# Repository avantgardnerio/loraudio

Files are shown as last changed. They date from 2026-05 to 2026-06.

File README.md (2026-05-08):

# open-oswst

Stealth LoRa radio mesh where the primary design principle is "only speak when spoken to".

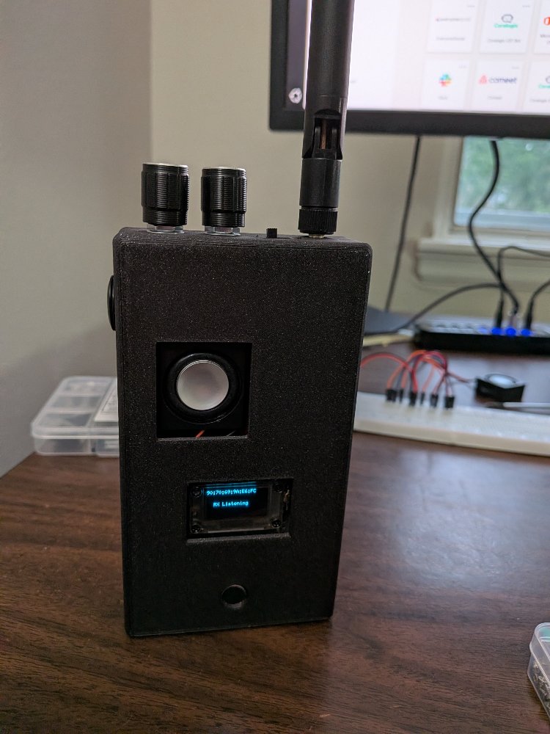
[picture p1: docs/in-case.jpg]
open-oswst radio in 3d printed case


## Hardware

- **Board**: [Heltec WiFi LoRa 32 V4](https://heltec.org/project/wifi-lora-32-v4/) (ESP32-S3 + SX1262, 863-928 MHz)
- **MCU**: ESP32-S3 rev 0.2, 16MB flash, 338 KiB RAM
- **Radio**: Semtech SX1262 LoRa transceiver, 915 MHz ISM band
- **Display**: SSD1306 128x64 OLED (I2C)

### Pin Map

| Function | GPIO |
|---|---|
| PRG button (PTT) | 0 (active LOW, internal pull-up) |
| White LED | 35 |
| Vext power enable | 36 (LOW = on) |
| OLED SDA | 17 |
| OLED SCL | 18 |
| OLED RST | 21 |
| LoRa SCK | 9 |
| LoRa MOSI | 10 |
| LoRa MISO | 11 |
| LoRa NSS | 8 |
| LoRa RST | 12 |
| LoRa DIO1 | 14 |
| LoRa BUSY | 13 |

## Dev Environment Setup

### Prerequisites

1. **Install Rust + Xtensa toolchain** via [espup](https://github.com/esp-rs/espup):

```bash
cargo install espup
espup install
```

2. **Create an ESP environment export script** (`~/export-esp.sh`):

```bash
export LIBCLANG_PATH="$HOME/.rustup/toolchains/esp/xtensa-esp32-elf-clang/esp-20.1.1_20250829/esp-clang/lib"
export PATH="$HOME/.rustup/toolchains/esp/xtensa-esp-elf/esp-15.2.0_20250920/xtensa-esp-elf/bin:$PATH"
```

The exact paths may vary — check `~/.rustup/toolchains/esp/` after `espup install`.

3. **Install flashing tools**:

```bash
cargo install espflash cargo-espflash ldproxy
```

4. **Optional**: install `picocom` for serial monitoring:

```bash
sudo apt install picocom
```

### Build

```bash
. ~/export-esp.sh
cargo build
```

ESP-IDF v5.5.x is downloaded automatically by `esp-idf-sys` on first build (takes a while).

### Flash

The firmware uses a custom partition table with a dedicated `open-oswst` NVS partition for device config. Since `espflash flash` overwrites the partition table with its own, you must re-write ours after flashing:

```bash
. ~/export-esp.sh

# 1. Flash firmware
espflash flash -p /dev/ttyACM0 target/xtensa-esp32s3-espidf/debug/open-oswst

# 2. Overwrite partition table with ours (espflash clobbers it in step 1)
espflash write-bin -p /dev/ttyACM0 0x8000 target/xtensa-esp32s3-espidf/debug/partition-table.bin

# 3. Write device config (only needed on first flash or to change config)
espflash write-bin -p /dev/ttyACM0 0xfad000 ~/phy/open-oswst_nvs.bin
```

Monitor separately:

```bash
picocom /dev/ttyACM0 -b 115200
```

### Device Config (NVS)

Device configuration lives in a dedicated `open-oswst` NVS partition at `0xfad000` (12KB), separate from the system NVS (PHY cal, WiFi, etc).

Generate a config image from `nvs_open-oswst.csv`:

```bash
# Generate NVS image (edit nvs_open-oswst.csv to change values)
python3 .embuild/espressif/python_env/idf5.5_py3.13_env/lib/python3.13/site-packages/esp_idf_nvs_partition_gen/nvs_partition_gen.py \
    generate nvs_open-oswst.csv ~/phy/open-oswst_nvs.bin 0x3000

# Flash to board
espflash write-bin -p /dev/ttyACM0 0xfad000 ~/phy/open-oswst_nvs.bin
```

Current config keys (namespace `config`):

| Key | Type | Values | Default |
|-----|---|---|---|
| `repeater` | u8 | 0=endpoint, 1=repeater | 0 |

There is also `nvs_config.py` for read-modify-write of the *system* NVS partition (preserving PHY cal data etc), but the dedicated partition approach above is preferred.

## Current Behavior

- Simplex push-to-talk voice radio over LoRa
- Hold **PRG button** (GPIO 0) to talk — audio is captured, Codec2-encoded at 1200 bps, and streamed as 4-frame LoRa packets (160ms audio each)
- Release to listen — received audio is decoded and played through I2S speaker (MAX98357A)
- OLED shows mode (RX Listening / TX Streaming / RX Audio) with RSSI and SNR on receive
- CSMA with preamble-aware jitter for collision avoidance
- Per-device config via dedicated NVS partition (repeater mode flag)
- **Next up**: repeater mesh relay

## Key Implementation Notes

- **Framework**: esp-idf-svc 0.52.1 (std Rust, not bare-metal)
- **Async**: `block_on` + `embassy_futures::select` for zero-polling PTT/RX racing
- **LoRa driver**: `lora-phy` (upstream git, 3.0.2-alpha) with `GenericSx126xInterfaceVariant`
- **GPIO type erasure**: `degrade_input()`/`degrade_output()` required for lora-phy's generic interface
- **SPI async**: `CONFIG_SPI_MASTER_ISR_IN_IRAM` disabled in `sdkconfig.defaults`
- **defmt workaround**: `defmt-discard.x` linker script discards defmt sections that break ESP-IDF flash layout
- **Stack**: 65536 bytes for main task (Codec2 init needs large stack temporaries)

## Project Structure

```
src/main.rs          # Entry point, channels, NVS config read
src/radio.rs         # SPI + LoRa init, IRQ-driven RX/TX loop, CSMA
src/app.rs           # PTT, ADC, OLED, Codec2, I2S speaker
partitions.csv       # Custom partition table (adds open-oswst NVS)
nvs_open-oswst.csv     # Default device config values
nvs_config.py        # Tool for read-modify-write of system NVS
sdkconfig.defaults   # ESP-IDF config overrides
defmt-discard.x      # Linker script to discard defmt sections
rust-toolchain.toml  # Pins to "esp" toolchain channel
build.rs             # Links defmt-discard.x
```

## Bill of Materials

### Handset (~$122)

| Component | Part | Qty | Est. Cost |
|---|---|-----|---|
| [MCU + LoRa + GPS](https://www.amazon.com/dp/B0GCD9W6JZ?ref=ppx_yo2ov_dt_b_fed_asin_title&th=1) | Heltec WiFi LoRa 32 V4 | 1 | $42 |
| [RF amplifier](https://www.amazon.com/dp/B0DQBJVR91?ref=ppx_yo2ov_dt_b_fed_asin_title) | AB-IOT-868 "Air Buddy" (902-928 MHz, bidirectional TX+LNA) | 1 | $26 |
| [Speaker amp](https://www.amazon.com/dp/B0DPJRLMDJ?ref=ppx_yo2ov_dt_b_fed_asin_title) | MAX98357A I2S Class D breakout | 1 | $3 |
| [Speaker](https://www.amazon.com/dp/B0BTP67F81?ref=ppx_yo2ov_dt_b_fed_asin_title&th=1) | 8 ohm 1W mini (JST-PH1.25mm) | 1 | $2.50 |
| [Microphone](https://www.amazon.com/dp/B0B7SP6GYX?ref=ppx_yo2ov_dt_b_fed_asin_title) | MAX9814 electret with AGC (analog out) | 1 | $4 |
| [Antenna](https://www.amazon.com/dp/B0D47HVCK7?ref=ppx_yo2ov_dt_b_fed_asin_title&th=1) | 5 dBi SMA whip (915 MHz) | 1 | $6 |
| [Battery](https://www.amazon.com/dp/B0FPCWFFYB?ref=ppx_yo2ov_dt_b_fed_asin_title) | YELUFT 1S 103450 3.7V 2000mAh LiPo (JST 1.25) | 1 | $24 |
| [encoder](https://www.amazon.com/dp/B07F24TRYG?ref=ppx_yo2ov_dt_b_fed_asin_title) | EC11 rotary encoder w/ push button (Taiss) | 2 | $1.25 |
| [Power switch](https://www.amazon.com/dp/B0DN69L9SG?ref=ppx_yo2ov_dt_b_fed_asin_title&th=1) | SS12F15 mini slide switch (SPDT) | 1 | $0.30 |
| [PTT button](https://www.amazon.com/dp/B015X34IP6?ref=ppx_yo2ov_dt_b_fed_asin_title&th=1) | Ulincos U16A1 16mm metal momentary, flush | 1 | $8 |
| [Speaker jack](https://www.amazon.com/dp/B01ASF0LW8?ref=ppx_yo2ov_dt_b_fed_asin_title) | 2.5mm TRS chassis mount (Calrad 30-714 or similar) | 1 | $0.66 |
| [Mic/PTT jack](https://www.amazon.com/dp/B00ZYWJ1DG?ref=ppx_yo2ov_dt_b_fed_asin_title) | 3.5mm TRS chassis mount w/ switch (CESS) | 1 | $2 |
| [F2F SMA](https://www.amazon.com/dp/B0FB3R5WRL?ref=ppx_yo2ov_dt_b_fed_asin_title&th=1) | Female to Female SMA | 1 | $1 |

## License

TBD

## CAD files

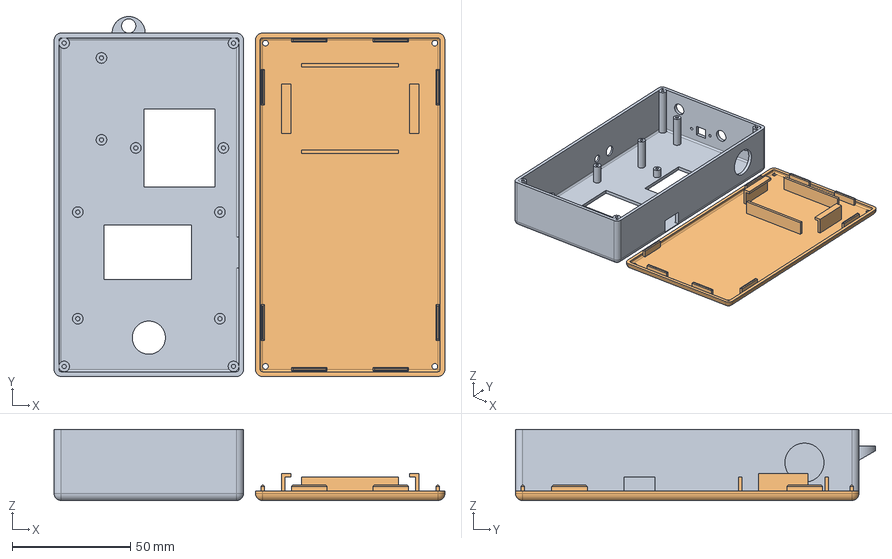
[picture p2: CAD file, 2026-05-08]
models/case.step
165.0 x 152.0 x 30.0 mm

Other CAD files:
models/case.stl

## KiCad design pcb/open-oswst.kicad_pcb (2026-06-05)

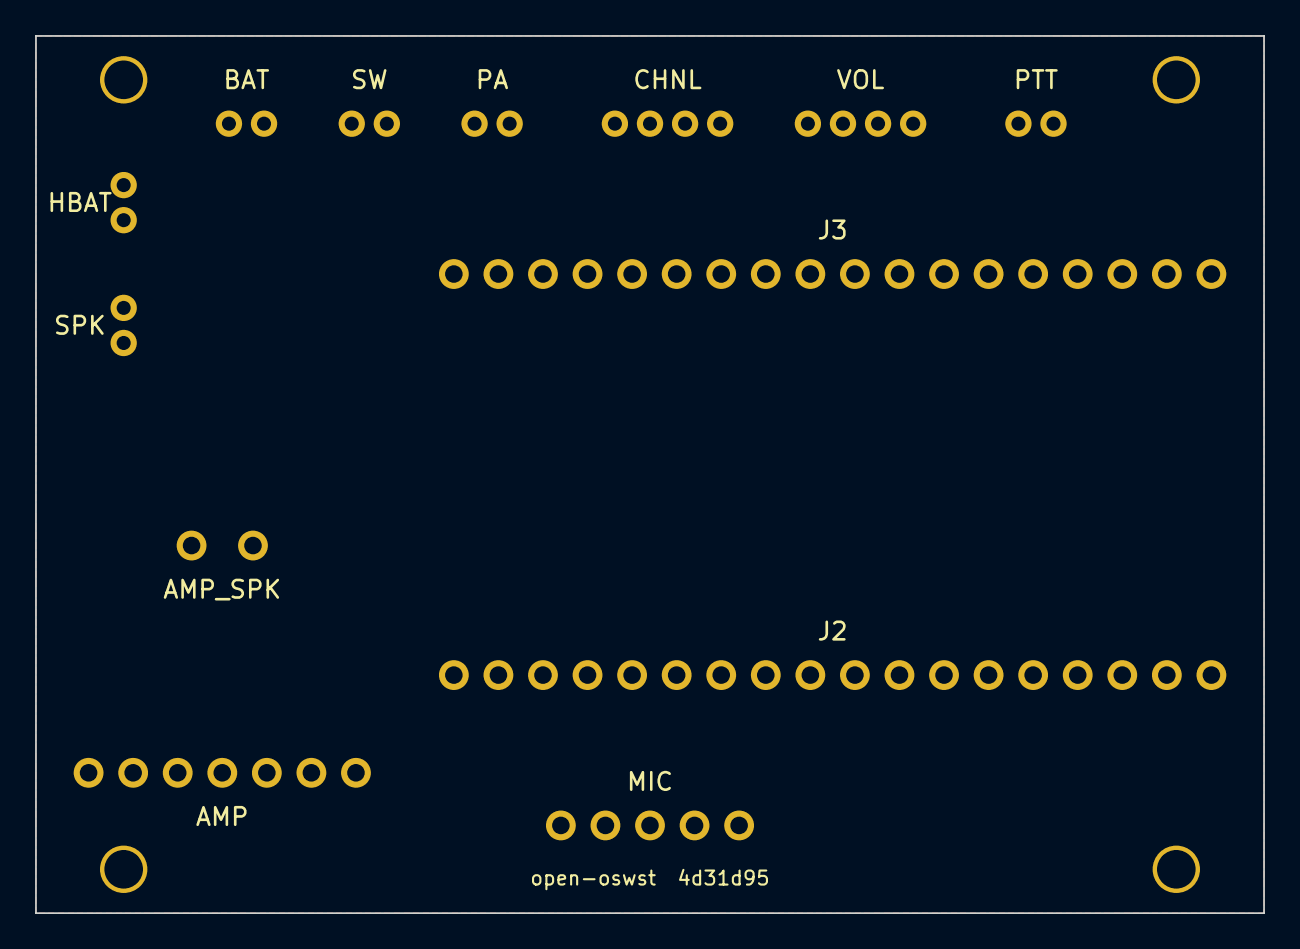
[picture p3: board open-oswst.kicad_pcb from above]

Board: 2 copper layers, 70.0 x 50.0 mm, 17 parts (0 on the bottom side), 17 nets, no tracks yet.

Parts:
AMP: PinHeader_1x7_P2.54mm
AMP_SPK: PinHeader_1x2_P3.5mm
BAT: JST_PH_B2B
CHNL: JST_PH_B4B
H1, H2, H3, H4: MountingHole_2.2mm
HBAT: JST_PH_B2B
J2, J3: PinHeader_1x18_P2.54mm
MIC: PinHeader_1x5_P2.54mm
PA: JST_PH_B2B
PTT: JST_PH_B2B
SPK: JST_PH_B2B
SW: JST_PH_B2B
VOL: JST_PH_B4B

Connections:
BCLK: AMP.BCLK, J2.GPIO47
CHNL_A: CHNL.A, J3.GPIO7
CHNL_B: CHNL.B, J3.GPIO6
CHNL_SW: CHNL.SW, J3.GPIO5
DIN: AMP.DIN, J2.GPIO33
GND: AMP.GND, BAT.-, CHNL.GND, HBAT.-, J2.GND, J3.GND, MIC.GND, PA.-, PTT.2, VOL.GND
LRC: AMP.LRC, J2.GPIO48
MIC_OUT: J3.GPIO4, MIC.OUT
PTT: J2.GPIO0, PTT.1
SPK+: AMP_SPK.+, SPK.+
SPK-: AMP_SPK.-, SPK.-
VBAT: BAT.+, SW.1
VOL_A: J3.GPIO3, VOL.A
VOL_B: J3.GPIO2, VOL.B
VOL_SW: J3.GPIO1, VOL.SW
VSW: HBAT.+, PA.+, SW.2
Ve: AMP.Vin, J2.Ve_a, J2.Ve_b, MIC.VDD

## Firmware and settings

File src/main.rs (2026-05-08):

mod app;
mod codec;
mod radio;
mod speaker;

use embassy_futures::join::join3;
use embassy_sync::blocking_mutex::raw::CriticalSectionRawMutex;
use embassy_sync::channel::Channel;
use esp_idf_svc::hal::gpio::PinDriver;
use esp_idf_svc::hal::peripherals::Peripherals;
use esp_idf_svc::hal::task::block_on;
use esp_idf_svc::nvs::{EspCustomNvsPartition, EspNvs};
use std::sync::atomic::AtomicBool;
use std::sync::Arc;
use std::thread;
use std::time::Duration;

// --- Channel message types ---

pub(crate) struct RxPacket {
    pub data: heapless::Vec<u8, 255>,
    pub rssi: i16,
    pub snr: i16,
}

pub(crate) struct TxRequest {
    pub data: heapless::Vec<u8, 255>,
}

// --- Channel instances (static, ISR-safe) ---

pub(crate) static RX_CHAN: Channel<CriticalSectionRawMutex, RxPacket, 2> = Channel::new();
pub(crate) static TX_CHAN: Channel<CriticalSectionRawMutex, TxRequest, 4> = Channel::new();

/// Speaker requests next audio packet from app
pub(crate) static SPK_REQ: Channel<CriticalSectionRawMutex, (), 1> = Channel::new();

/// Audio frames for speaker — each is one 40ms stereo frame (640 i16).
/// Capacity 8 = 2 packets worth of frames.
pub(crate) static SPK_FRAMES: Channel<CriticalSectionRawMutex, Arc<[i16]>, 8> = Channel::new();

/// Whether this device is a repeater, read from NVS at boot.
pub(crate) static IS_REPEATER: AtomicBool = AtomicBool::new(false);

/// Read the base MAC address from eFuse
fn get_mac() -> [u8; 6] {
    let mut mac = [0u8; 6];
    unsafe {
        esp_idf_svc::sys::esp_read_mac(
            mac.as_mut_ptr(),
            esp_idf_svc::sys::esp_mac_type_t_ESP_MAC_WIFI_STA,
        );
    }
    mac
}

fn main() {
    esp_idf_svc::sys::link_patches();
    esp_idf_svc::log::EspLogger::initialize_default();
    log::info!("open-oswst starting...");

    let peripherals = Peripherals::take().unwrap();

    // Enable Vext power (GPIO36 LOW = on) — must keep _vext alive or power turns off
    let mut _vext = PinDriver::output(peripherals.pins.gpio36).unwrap();
    _vext.set_low().unwrap();
    thread::sleep(Duration::from_millis(50));

    // Read config from dedicated NVS partition
    let nvs_partition = EspCustomNvsPartition::take("open-oswst").unwrap();
    let nvs = EspNvs::new(nvs_partition, "config", false).unwrap();
    let repeater = nvs.get_u8("repeater").unwrap().unwrap_or(0) != 0;
    IS_REPEATER.store(repeater, std::sync::atomic::Ordering::Relaxed);
    log::info!("Config: repeater={}", repeater);

    // Get MAC for display
    let mac = get_mac();
    let mut mac_str = heapless::String::<18>::new();
    let _ = core::fmt::write(
        &mut mac_str,
        format_args!(
            "{:02X}:{:02X}:{:02X}:{:02X}:{:02X}:{:02X}",
            mac[0], mac[1], mac[2], mac[3], mac[4], mac[5]
        ),
    );

    // Spawn codec thread with sync channel (capacity 2 to allow pipelining)
    let (codec_tx, codec_rx) = std::sync::mpsc::sync_channel::<codec::CodecRequest>(2);
    std::thread::Builder::new()
        .name("codec".into())
        .stack_size(32768)
        .spawn(move || codec::run(codec_rx))
        .unwrap();

    block_on(async {
        let radio_fut = radio::init(radio::Peripherals {
            spi: peripherals.spi2,
            sck: peripherals.pins.gpio9.into(),
            mosi: peripherals.pins.gpio10.into(),
            miso: peripherals.pins.gpio11.into(),
            nss: peripherals.pins.gpio8.into(),
            reset: peripherals.pins.gpio12.into(),
            dio1: peripherals.pins.gpio14.into(),
            busy: peripherals.pins.gpio13.into(),
        })
        .await;

        let speaker_fut = speaker::init(speaker::Peripherals {
            i2s: peripherals.i2s0,
            spk_bclk: peripherals.pins.gpio3.into(),
            spk_din: peripherals.pins.gpio5.into(),
            spk_ws: peripherals.pins.gpio4.into(),
        })
        .await;

        let app_fut = app::init(
            app::Peripherals {
                ptt: peripherals.pins.gpio0.into(),
                audio_in: peripherals.pins.gpio7,
                adc: peripherals.adc1,
                i2c: peripherals.i2c0,
                oled_sda: peripherals.pins.gpio17.into(),
                oled_scl: peripherals.pins.gpio18.into(),
                oled_rst: peripherals.pins.gpio21.into(),
            },
            mac_str,
            codec_tx,
        )
        .await;

        log::info!("All systems ready");
        join3(radio_fut, app_fut, speaker_fut).await;
    });
}

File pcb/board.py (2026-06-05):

#!/usr/bin/env python3
"""Generate the open-oswst PCB."""

import subprocess
from kicad import Board

board = Board()
git_sha = subprocess.check_output(["git", "rev-parse", "--short", "HEAD"], text=True).strip()

# 70x50mm landscape, centered on A4 (297x210mm)
BX, BY = 113, 113  # board origin
BW, BH = 70, 50    # board size
INSET_LR = 5        # hole center distance from left/right edges
INSET_TB = 2.5      # hole center distance from top/bottom edges

board.add_rect(BX, BY, BW, BH)

for x in (BX + INSET_LR, BX + BW - INSET_LR):
    for y in (BY + INSET_TB, BY + BH - INSET_TB):
        board.add_mounting_hole(x, y, drill=2.2)

# Connectors along top edge — fit between drill holes (INSET_LR)
cx, cy = BX + INSET_LR + 7, BY + 5
board.add_jst_ph(cx, cy, pins=2, label="BAT",
                 pad_labels=["+", "-"], pad_nets=["VBAT", "GND"]); cx += 7
board.add_jst_ph(cx, cy, pins=2, label="SW",
                 pad_nets=["VBAT", "VSW"]); cx += 7
board.add_jst_ph(cx, cy, pins=2, label="PA",
                 pad_labels=["+", "-"], pad_nets=["VSW", "GND"]); cx += 10
board.add_jst_ph(cx, cy, pins=4, label="CHNL",
                 pad_labels=["A", "B", "SW", "GND"],
                 pad_nets=["CHNL_A", "CHNL_B", "CHNL_SW", "GND"]); cx += 11
board.add_jst_ph(cx, cy, pins=4, label="VOL",
                 pad_labels=["A", "B", "SW", "GND"],
                 pad_nets=["VOL_A", "VOL_B", "VOL_SW", "GND"]); cx += 10
board.add_jst_ph(cx, cy, pins=2, label="PTT",
                 pad_nets=["PTT", "GND"])

# HBAT: feeds VSW out to Heltec's onboard SH1.25-2P LiPo input via an M2M pigtail.
# Heltec's battery input accepts 3.3-4.2V (per datasheet 3.2), so raw LiPo is correct here.
# Placed above SPK so VSW from BAT/SW (top of board) doesn't cross the SPK+/SPK- traces.
board.add_jst_ph(BX + 5, BY + INSET_TB + 7, pins=2, label="HBAT", angle=90,
                 pad_labels=["+", "-"], pad_nets=["VSW", "GND"])

# SPK connector on left edge (rotated 90°, routes down to AMP_SPK)
board.add_jst_ph(BX + 5, BY + INSET_TB + 14, pins=2, label="SPK", angle=90,
                 pad_labels=["-", "+"], pad_nets=["SPK-", "SPK+"])

# Heltec V4 headers — two 18-pin rows
J3_SPAN = 17 * 2.54  # 18 pins, 17 gaps
HELTEC_WIDTH = 22.86  # distance between J3 and J2 header rows
HY = BY + BH / 2 - HELTEC_WIDTH / 2  # J3 y (top row)

board.add_header(BX + BW - 3 - J3_SPAN / 2, HY, pins=18, label="J3",
                 pad_labels=["GPIO7", "GPIO6", "GPIO5", "GPIO4", "GPIO3", "GPIO2",
                             "GPIO1", "GPIO38", "GPIO39", "GPIO40", "GPIO41", "GPIO42",
                             "GPIO45", "GPIO46", "GPIO37", "3V3a", "3V3b", "GND"],
                 pad_nets=["CHNL_A", "CHNL_B", "CHNL_SW", "MIC_OUT", "VOL_A", "VOL_B",
                           "VOL_SW", None, None, None, None, None,
                           None, None, None, None, None, "GND"])

# Heltec V4 J2 header (right side, pin 18→1 top to bottom)
J2_SPAN = J3_SPAN  # same 18 pins
board.add_header(BX + BW - 3 - J2_SPAN / 2, HY + HELTEC_WIDTH, pins=18, label="J2",
                 pad_labels=["GPIO19", "GPIO20", "GPIO21", "GPIO26", "GPIO48", "GPIO47",
                             "GPIO33", "GPIO34", "GPIO35", "GPIO36", "GPIO0", "RST",
                             "GPIO43", "GPIO44", "Ve_b", "Ve_a", "5V", "GND"],
                 pad_nets=[None, None, None, None, "LRC", "BCLK",
                           "DIN", None, None, None, "PTT", None,
                           None, None, "Ve", "Ve", None, "GND"])

# Board headers along bottom edge
board.add_header(BX + BW / 2, BY + BH - 5, pins=5, label="MIC",
                 pad_labels=["AR", "OUT", "GAIN", "VDD", "GND"],
                 pad_nets=[None, "MIC_OUT", None, "Ve", "GND"])
AMP_X = BX + 3 + 3 * 2.54
AMP_Y = BY + BH - 3 - 5
board.add_header(AMP_X, AMP_Y, pins=7, label="AMP", angle=180,
                 pad_labels=["Vin", "GND", "SD", "GAIN", "DIN", "BCLK", "LRC"],
                 pad_nets=["Ve", "GND", None, None, "DIN", "BCLK", "LRC"])
board.add_header(AMP_X, AMP_Y - 12.954, pins=2, label="AMP_SPK", angle=180,
                 pitch=3.5, pad_labels=["+", "-"], pad_nets=["SPK+", "SPK-"])

# Silkscreen — project name and git SHA
board.add_text(BX + BW / 2, BY + BH - 2, f"open-oswst  {git_sha}", size=0.8, thickness=0.12)

# Ground plane — GND zone covering full board, both copper layers
board.add_zone("GND", [
    (BX, BY), (BX + BW, BY), (BX + BW, BY + BH), (BX, BY + BH),
], clearance=0.25, thermal_gap=0.3, thermal_bridge_width=0.3)

board.save("open-oswst.kicad_pcb")

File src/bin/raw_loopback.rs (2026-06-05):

//! Raw audio loopback test (no Codec2) — hold PTT to record, release to play back raw PCM.
//! Build & flash: cargo build --bin raw_loopback && espflash flash -p /dev/ttyACM1 --partition-table target/xtensa-esp32s3-espidf/debug/partition-table.bin target/xtensa-esp32s3-espidf/debug/raw_loopback

use embedded_graphics::mono_font::ascii::FONT_10X20;
use embedded_graphics::mono_font::MonoTextStyleBuilder;
use embedded_graphics::pixelcolor::BinaryColor;
use embedded_graphics::prelude::*;
use embedded_graphics::text::Text;
use esp_idf_svc::hal::adc::continuous::config::Config as AdcContConfig;
use esp_idf_svc::hal::adc::continuous::{AdcDriver as AdcContDriver, AdcMeasurement, Attenuated};
use esp_idf_svc::hal::delay::BLOCK;
use esp_idf_svc::hal::gpio::{AnyIOPin, PinDriver, Pull};
use esp_idf_svc::hal::i2c::config::Config as I2cConfig;
use esp_idf_svc::hal::i2c::I2cDriver;
use esp_idf_svc::hal::i2s::config::{
    Config as I2sChannelConfig, DataBitWidth, SlotMode, StdClkConfig, StdConfig, StdGpioConfig,
    StdSlotConfig,
};
use esp_idf_svc::hal::i2s::{I2sDriver, I2sTx};
use esp_idf_svc::hal::peripherals::Peripherals;
use esp_idf_svc::hal::units::Hertz;
use ssd1306::prelude::*;
use ssd1306::{I2CDisplayInterface, Ssd1306};
use std::thread;
use std::time::Duration;

/// Max recording: 5 seconds at 8kHz
const MAX_SAMPLES: usize = 40000;

/// Convert 12-bit unsigned ADC to signed 16-bit PCM.
fn adc_to_pcm(sample: &AdcMeasurement) -> i16 {
    (sample.data() as i16 - 2048) * 16
}

fn pcm_as_bytes(pcm: &[i16]) -> &[u8] {
    unsafe { core::slice::from_raw_parts(pcm.as_ptr() as *const u8, pcm.len() * 2) }
}

fn main() {
    esp_idf_svc::sys::link_patches();
    esp_idf_svc::log::EspLogger::initialize_default();
    log::info!("Raw audio loopback test starting...");

    let p = Peripherals::take().unwrap();

    // Vext power on (GPIO36 LOW)
    let mut vext = PinDriver::output(p.pins.gpio36).unwrap();
    vext.set_low().unwrap();
    thread::sleep(Duration::from_millis(50));

    // PTT button (GPIO0, active LOW)
    let button = PinDriver::input(p.pins.gpio0, Pull::Up).unwrap();

    // ADC continuous for mic on GPIO4 (ADC1_CH3) at 8kHz — rev4 pinout
    let adc_cfg = AdcContConfig::new()
        .sample_freq(Hertz(8000))
        .frame_measurements(320)
        .frames_count(2);
    let mut adc = AdcContDriver::new(p.adc1, &adc_cfg, Attenuated::db12(p.pins.gpio4)).unwrap();

    // I2S TX for speaker — rev4 pinout: BCLK=47, WS=48, DIN=33
    let i2s_cfg = StdConfig::new(
        I2sChannelConfig::new()
            .dma_buffer_count(8)
            .frames_per_buffer(320)
            .auto_clear(true),
        StdClkConfig::from_sample_rate_hz(8000),
        StdSlotConfig::philips_slot_default(DataBitWidth::Bits16, SlotMode::Stereo),
        StdGpioConfig::default(),
    );
    let mut i2s = I2sDriver::<I2sTx>::new_std_tx(
        p.i2s0,
        &i2s_cfg,
        p.pins.gpio47, // BCLK
        p.pins.gpio33, // DIN
        None::<AnyIOPin>,
        p.pins.gpio48, // WS
    )
    .unwrap();
    i2s.tx_enable().unwrap();

    // OLED init
    let mut oled_rst = PinDriver::output(p.pins.gpio21).unwrap();
    oled_rst.set_low().unwrap();
    thread::sleep(Duration::from_millis(50));
    oled_rst.set_high().unwrap();
    thread::sleep(Duration::from_millis(50));
    let i2c = I2cDriver::new(
        p.i2c0,
        p.pins.gpio17,
        p.pins.gpio18,
        &I2cConfig::default(),
    )
    .unwrap();
    let interface = I2CDisplayInterface::new(i2c);
    let mut display = Ssd1306::new(interface, DisplaySize128x64, DisplayRotation::Rotate0)
        .into_buffered_graphics_mode();
    display.init().unwrap();
    display.set_brightness(Brightness::BRIGHTEST).unwrap();
    let style = MonoTextStyleBuilder::new()
        .font(&FONT_10X20)
        .text_color(BinaryColor::On)
        .build();

    let show_status = |display: &mut ssd1306::Ssd1306<_, _, ssd1306::mode::BufferedGraphicsMode<_>>, msg: &str| {
        display.clear_buffer();
        let _ = Text::new(msg, Point::new(10, 38), style).draw(display);
        let _ = display.flush();
    };

    // Heap buffers
    let mut mic_buf = vec![AdcMeasurement::new(); 320];
    let mut rec_buf = vec![0i16; MAX_SAMPLES];
    let mut stereo_buf = vec![0i16; 640]; // 320 mono → 640 stereo interleaved

    log::info!("Ready — hold PTT to record (max 5s), release to play raw PCM");
    adc.start().unwrap();
    show_status(&mut display, "IDLE");

    loop {
        // Wait for PTT press
        while button.is_high() {
            thread::sleep(Duration::from_millis(10));
        }

        // --- Record ---
        log::info!("Recording...");
        show_status(&mut display, "LISTENING");
        let _ = adc.read(&mut mic_buf, 0); // drain stale
        let mut rec_len: usize = 0;

        while button.is_low() && rec_len < MAX_SAMPLES {
            let count = adc.read(&mut mic_buf, 100).unwrap_or(0);
            let remaining = MAX_SAMPLES - rec_len;
            let n = count.min(remaining);
            for i in 0..n {
                rec_buf[rec_len + i] = adc_to_pcm(&mic_buf[i]);
            }
            rec_len += n;
        }
        log::info!("Recorded {} samples ({}ms)", rec_len, rec_len / 8);

        // --- Play back raw ---
        log::info!("Playing raw...");
        show_status(&mut display, "PLAYING");

        // Play in 320-sample chunks (40ms each)
        let mut pos = 0;
        while pos < rec_len {
            let chunk_end = (pos + 320).min(rec_len);
            let chunk = &rec_buf[pos..chunk_end];

            // Mono → stereo interleave
            for (i, &sample) in chunk.iter().enumerate() {
                stereo_buf[i * 2] = sample;
                stereo_buf[i * 2 + 1] = sample;
            }
            let stereo_bytes = pcm_as_bytes(&stereo_buf[..chunk.len() * 2]);
            i2s.write_all(stereo_bytes, BLOCK).unwrap();
            pos = chunk_end;
        }

        log::info!("Playback done");
        show_status(&mut display, "IDLE");
    }
}

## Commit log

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2026-04-22 Add OLED display support with SSD1306 over I2C
    Enable Vext power (GPIO 36) for display, reset via GPIO 21,
    draw text using embedded-graphics. LED continues blinking.
    [main.rs]
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2026-04-23 Fix RX by reverting to two-way select, pace TX off mic DMA frames
    Three-way select with VU meter was interrupting RX every 40ms, preventing
    packet reception. Revert to select(rx, button) for reliable continuous RX.
    TX loop now awaits mic DMA buffers instead of fixed 200ms timer. VU meter
    removed — mic DMA validated, no longer needed.
    [main.rs]
2026-04-23 Integrate Codec2 1200bps voice encoding into TX/RX path
    ADC mic samples are now encoded with Codec2 MODE_1200 (320 i16 samples →
    6 bytes) and transmitted as compressed voice frames over LoRa. RX side
    decodes and logs stats (decode time, peak amplitude). Stack increased to
    64KB and Codec2 instances are Box-allocated to avoid async future overflow.
    [app.rs]
2026-04-23 Run CPU at 240MHz and enable thin LTO for Codec2 headroom
    240MHz drops encode from 38ms to 28ms (12ms headroom on 40ms budget).
    Thin LTO shrinks flash from 901KB to 875KB but doesn't improve encode
    speed further. Combined with opt-level "s" this gives comfortable
    real-time margin with no threading needed.
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2026-04-24 Remove jitter buffer, decode and play frames immediately
    Prepares for packet sequence buffer by removing the accumulate-then-play
    jitter buffer. Frames now decode and write to I2S inline, reusing a single
    stereo_frame buffer instead of heap-allocating per frame.
    [app.rs]
2026-04-24 Add packet sequence tracking with diff-based accept/reject
    Compute signed mod-16 distance between incoming seq and expected seq.
    Drop old packets (-3..-1), reset txid lock on unrealistic gaps (-8..-4
    or 4+), play on-time (0) and ahead (1..3) packets. Seed last_played_seq
    on first packet so diff=0 for stream start.
    [app.rs]
2026-04-24 Add packet sequence buffer for reordering out-of-order RX
    Incoming packets are placed into a 16-slot ring buffer indexed by seq.
    After each insert, drain forward from last_played_seq+1, decoding and
    playing consecutive packets until a gap is hit. Early/late/unrealistic
    packets are dropped or trigger txid reset.
    [app.rs]
2026-04-24 Clear seq_buf on RX state reset and PTT press
    Add reset_rx_state() to zero cur_txid, last_played_seq, and seq_buf.
    Called on unrealistic seq gaps (old/new) and when PTT is pressed, so
    stale buffered packets never leak across transmissions.
    [app.rs]
2026-04-24 Add CSMA with preamble-aware jitter for TX collision avoidance
    Instead of explicit CAD, use IRQ-driven preamble detection from
    RX continuous mode as free channel sensing. Before TX:
    - If channel busy (preamble in progress), wait for RX to finish
    - Random 0-19ms jitter while still listening for new preambles
    - If someone starts TX during jitter, wait and retry with new jitter
    - If jitter expires with channel clear, TX immediately
    Decentralized, no TDMA — just listen and be polite.
    [radio.rs]
2026-04-25 Move repeater relay after dedup to fix duplicate relays and missing EOT
    Relay was firing before dedup/EOT checks, causing two problems:
    1. Duplicate packets from multiple paths were all retransmitted
    2. EOT packets were skipped (continue before EOT handler)
    Now relay happens post-dedup in two places: inside the EOT handler
    and in the 0..=2 seq-diff arm. Repeater still decodes+displays for
    RSSI/SNR monitoring.
    [app.rs]
2026-04-28 [WIP] add case model
    [case.step, case.stl]
2026-04-28 [WIP] move antenna to left, add slider + encoder holes, widen case to 80mm
    [case.step, case.stl]
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2026-04-28 Fix Heltec pin layout and position on stripboard
    Swap J3/J2 headers to match physical orientation (J3 top, J2 bottom),
    split merged 3V3 and Ve pins into separate entries, and move Heltec
    to col 0 so USB-C aligns with the case hole.
2026-04-28 Refine stripboard layout: spacing, labels, and pin label rotation
    Move Heltec to row 1 and sub-boards to row 13 for bridge wiring room.
    Jumpers offset to adjacent rows to avoid double-wiring holes. Pin labels
    auto-rotate inward based on pin run direction. Trace cuts on row 12.
    Fix label y-offset to sit on target row.
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2026-04-29 Vertical traces, mid-Heltec cuts, erase primitive
    Fix copper side to render vertical traces matching the GENNEL stripboard.
    Add full-width cuts on row 6 (between Heltec headers) and row 12
    (between Heltec and sub-boards). Add erase() primitive for scratching
    away gaps between adjacent pads to connect them horizontally.
2026-05-02 Thinner lid, corner L-bracket guides, 3 screw posts with countersinks
    Halve lid from 8mm to 4mm (bottom now 26mm). Add L-bracket guide
    tabs at all 4 corners for lid alignment. Add 3 full-height screw
    posts at 3 corners (by speaker, both sides of mic) with countersunk
    M2 clearance holes in the lid.
    [case.step, case.stl]
2026-05-02 Dial in component holes and grow case for real-world fit
    - Speaker hole 28→28.5mm, encoder 7→7.2mm, PTT 16→16.5mm (recentered)
    - SMA 6.5→7mm, shifted 3mm toward outside wall
    - Kenwood jacks: 3.5→6mm, 2.5→4mm for actual hole sizes
    - USB-C 9x4→10x5mm, dropped 10mm toward floor
    - Screen hole shifted 7.5mm toward center
    - PA posts raised to 11mm (above 6mm perfboard posts), moved 2mm inward
    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
    [case.step, case.stl]
2026-05-02 Case fit round 3: clearances, SMA slot, guide fixes, component spacing
    - SMA hole → stadium slot for assembly, shifted 2mm toward left wall
    - Lid guides: halved depth (2.5mm), 10mm inboard to clear screw posts,
    flush with lid walls (no gap), chamfered bottom edges for lead-in
    - Speaker hole 30x33mm (rectangular, was 28.5mm square)
    - Power slider 12x8mm, PTT 8mm toward encoders, speaker 20mm down
    - Top controls shifted 5mm left to clear lid screw post
    - Kenwood jacks +1mm radius each
    [case.step, case.stl]
2026-05-04 Raise amp posts above controls, fix SMA and post clearance
    - Raise amp posts to 18mm (6mm below case side tops) to clear power switch
    - Move bottom amp post down 1 radius (2.5mm) to clear module
    - SMA hole simplified to single circle at raised amp height
    - Decouple controls (slider, encoders) and USB-C from amp height
    - USB-C now referenced from perfboard post height
    [case.step, case.stl]
2026-05-04 Case fit round 4: slider, speaker posts, Kenwood jack sizing
    - Power slider: taller (+1mm) and narrower (-1.5mm) for better fit
    - Speaker screw posts: 4mm tall (6mm minus floor), flush mount
    - Kenwood jacks: shrink holes to match real-world measurements (6.4/4.6mm)
    - Kenwood wall recess: 1mm pocket for nut clearance on thin jack threads
    [case.step, case.stl]
2026-05-04 Add 4th lid post, shift amp inward, decouple controls from amp X
    - Move amp posts 5mm toward center (FROM_LEFT 13→18) to clear new top-left lid post
    - Add 4th lid screw post in top-left corner
    - Decouple top wall controls from amp X position so they don't shift with amp
    [case.step, case.stl]
2026-05-04 [WIP] geometry fixes
    [case.step, case.stl]
2026-05-04 Add battery retention clips to X-axis cradle walls
    [case.step, case.stl]
2026-05-04 Case v1.0-alpha: battery wall height, speaker post spacing, slider cutout
    - BATT_WALL_H 6→11mm to properly retain battery
    - Speaker posts 38→37mm apart (0.5mm inward each side)
    - Slider cutout 11.5×9→7×3.5mm (bottom-mount, slider nub only)
    [case.step, case.stl]
2026-05-04 Case fit round 5: screen, slider, battery wall tweaks
    - Screen hole shifted 8mm left, enlarged +2mm per side
    - Slider cutout: fix depth to punch through wall, keep 3.5mm height
    - Battery walls: embed 1mm into lid, reduce height 11→8mm
    - Speaker posts: tighten 0.5mm per side
    [case.step, case.stl]
2026-05-04 [WIP] Case fit round 6: USB-C, perf posts, screen protrusion
    [case.step, case.stl]
2026-05-05 Case fit round 7: functional closed case
    - Mic hole 10→14mm diameter
    - Speaker posts 9→5mm height
    - Battery compartment shifted 15mm down to clear PA board
    - USB-C hole lowered to fillet edge, sized to 6mm tall
    - Perf posts raised to 11mm
    - Power slider shifted 2mm toward encoders
    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
    [case.step, case.stl]
2026-05-05 fix USB
    [case.step, case.stl]
2026-05-05 Add lanyard loop to case for hanging repeaters from trees
    14mm semicircle with 6mm hole, sized for 550 cord. Protrudes from
    top wall aligned with power switch.
    [case.step, case.stl]
2026-05-05 taper lanyard
    [case.step, case.stl]
2026-05-06 Add raw loopback test, improve audio test bins
    - Add raw_loopback bin: PTT record→play without Codec2 (isolates hardware)
    - audio_test: add OLED status (IDLE/LISTENING/PLAYING), upgrade to MODE_3200
    - mic_test: fix VU bar overlapping peak label
    [mic_test.rs, raw_loopback.rs]
2026-05-08 generate kicad
    [loraudio.kicad_pcb]
2026-05-08 Add mounting holes and split KiCad generator into library + board script
    [loraudio.kicad_pcb]
2026-05-08 Add JST-PH through-hole connector for speaker
    [loraudio.kicad_pcb]
2026-05-08 Add JST connectors for battery, PA power, PTT and power switch
    JST-PH 2.0mm for SPK, BAT, PTT, PWR; JST-SH 1.25mm for PA.
    All through-hole, single row along top edge.
    [loraudio.kicad_pcb]
2026-05-08 Add mic header and generic pin header to KiCad generator
    5-pin 2.54mm header for MAX9814 mic board, centered on bottom edge.
    Also adds add_header() method for standard pitch pin headers.
    [loraudio.kicad_pcb]
2026-05-08 Add speaker amp header to bottom edge
    7-pin 2.54mm header for MAX98357A, left of centered mic header.
    [loraudio.kicad_pcb]
2026-05-08 Add net support to KiCad generator for autorouting
    Pads now carry net assignments (GND, VBAT, I2S_BCLK, etc.)
    so Freerouting can automatically route traces between them.
    [loraudio.kicad_pcb]
2026-05-08 Add GND net only, add design rules and mask layers
    Ground net connects BAT-, PA-, PTT, AMP GND, and MIC GND.
    All other connections left unassigned for now.
    [loraudio.kicad_pcb]
2026-05-08 Add Heltec V4 J3 header (18-pin) to carrier board
    [loraudio.kicad_pcb]
2026-05-08 Add Heltec V4 J2 header and center both rows on board
    [loraudio.kicad_pcb]
2026-05-08 Wire power path: BAT+ → SW → PA+ and Heltec 3V3
    [loraudio.kicad_pcb]
2026-05-08 Wire Heltec 3V3 to AMP Vin and MIC VDD
    [loraudio.kicad_pcb]
2026-05-08 Wire I2S (BCLK/LRC/DIN), mic, and PTT nets
    [loraudio.kicad_pcb]
2026-05-08 ground plane
    [loraudio.kicad_pcb]
2026-05-08 ground plane: reduce clearance to 0.25mm, add island removal settings
    Fixes isolated GND islands around densely-packed top-edge connectors (PTT).
    [loraudio.kicad_pcb]
2026-05-08 Rename loraudio → open-oswst across entire project
    Package, binary, NVS partition, PCB, scripts, docs, and generated
    artifacts all updated to match the new repo name.
    [case.step, nvs_open-oswst.csv, open-oswst.kicad_pcb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]
2026-05-08 Add rotary encoder connectors to PCB
    Two 4-pin JST-PH connectors (ENC1, ENC2) for EC11 rotary encoders
    with push buttons (A, B, SW, GND). Wired to GPIO 1/2/6 and 33/47/48.
    Rebalanced top-edge connector spacing to fit all 7 connectors.
    [open-oswst.kicad_pcb]
2026-05-08 PCB: add encoders, rename labels, optimize GPIO locality
    - Rename ENC1→VOL, ENC2→CHNL
    - Move SPK to end of top-edge connector row
    - Swap I2S (BCLK/LRC/DIN) to J2 GPIO 33/47/48 (near AMP)
    - Move CHNL to J3 GPIO 5/6/7 (near top-edge connector)
    - Group J3 pins: VOL(1,2,3), MIC(4), CHNL(5,6,7)
    [open-oswst.kicad_pcb]
2026-05-08 PCB: use M2 mounting holes (2.2mm drill)
    [open-oswst.kicad_pcb]
2026-05-08 PCB: add silkscreen text, USLetter paper, M2 holes
    - Add project name + git SHA to front silkscreen
    - Fix paper size to USLetter for 1:1 printing
    - Add add_text() method to PCB DSL
    [open-oswst.kicad_pcb]
2026-05-08 PCB: reorder top-edge connectors (BAT SW PA PTT VOL CHNL SPK)
    [open-oswst.kicad_pcb]
2026-05-08 PCB: fix connector types to match actual parts
    - BAT: JST-PH → JST-SH (1.25mm) to match battery connector
    - PA: JST-SH → JST-PH (2.0mm) for JST-PH cable
    - SPK: JST-PH → JST-ZH (1.5mm) to match speaker connector
    - Flip SPK pin order to uncross traces
    - Add add_jst_zh() to PCB DSL
    [open-oswst.kicad_pcb]
2026-05-11 fix pinout
    [open-oswst.kicad_pcb]
2026-05-13 PCB: fix connector types and MIC pin order
    - BAT: JST-SH → JST-PH (2.0mm, standard LiPo connector)
    - SPK: JST-PH → JST-ZH (1.5mm, matches speaker connector)
    - Fix MIC header pin order to match actual board (GND,VDD,GAIN,OUT,AR)
    - Reduce thermal gap/bridge to 0.3mm to fix DRC spoke errors
    - Add add_text() and add_jst_zh() to PCB DSL
    - Switch paper to USLetter for 1:1 printing
    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
    [open-oswst.kicad_pcb]
2026-05-18 PCB: standardize all JST connectors on 2mm PH pitch
    SPK was JST-ZH (1.5mm); now JST-PH (2.0mm) like all others.
    Increased CHNL→SPK spacing to 10mm to fit wider housing.
    Removed unused add_jst_sh and add_jst_zh from kicad.py.
    [open-oswst.kicad_pcb]
2026-05-18 PCB: match drill holes to case, relayout top connectors, move SPK to right edge
    Mounting holes changed from 3mm uniform inset to 5mm LR / 2.5mm TB to
    match existing case perfboard posts (60x45mm pattern). Top-edge connectors
    shifted right and tightened (PTT→VOL 10mm, VOL→CHNL 11mm). SPK moved to
    right edge (rotated 90°) to free space. Removed unused JST-SH/ZH methods.
    [open-oswst.kicad_pcb]
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2026-05-28 bringup: add OLED/pin test bins, retarget speaker I2S for flipped board
    Board 3's fabbed PCB has J2/J3 footprints flipped, so peripherals land on
    different GPIOs than board.py intended (full remap in memory pcb-rev4).
    Confirmed during bringup: speaker I2S works on GPIO1/2/3 (440Hz tone heard).
    - speaker_test: retarget I2S to GPIO1/2/3 (BCLK/LRC/DIN) + live OLED
    "writes" counter to distinguish a running program from a dead one
    - hello_world: minimal OLED test (Vext + I2C + SSD1306) to prove the board
    - io_test: PTT-stepped pin driver — drives GPIO33/47/48 HIGH one at a time
    with on-screen label, for multimeter continuity probing at the AMP pads
    These target the flipped board; rev4 wil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
    [hello_world.rs, io_test.rs, speaker_test.rs]
2026-05-28 oriented correctly
    [open-oswst.kicad_pcb]
2026-05-28 correct side of board
    [open-oswst.kicad_pcb]
2026-05-28 move spkr
    [open-oswst.kicad_pcb]
2026-05-28 good rev
    [open-oswst.kicad_pcb]
2026-06-05 rev5 :(
    [open-oswst.kicad_pcb]
